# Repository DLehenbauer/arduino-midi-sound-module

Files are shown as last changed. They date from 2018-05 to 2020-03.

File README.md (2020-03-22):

# Arduino MIDI Sound Module
Turn your Arduino Uno into a 16-voice wavetable synthesizer/MIDI sound generator.

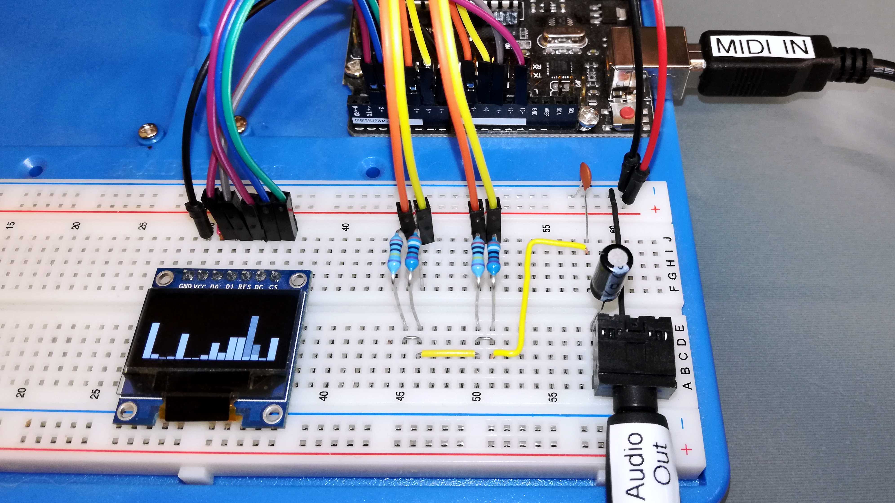
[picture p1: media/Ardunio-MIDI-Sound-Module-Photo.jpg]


# General MIDI Subset
Implements the most commonly used features of the General MIDI 1.0 standard, including:
* 128 standard instruments
* 45 percussion instruments
* 16 note polyphony with key velocity
* Note on/off, program change, pitch bend, channel volume, all notes and all sounds off.

# Demo

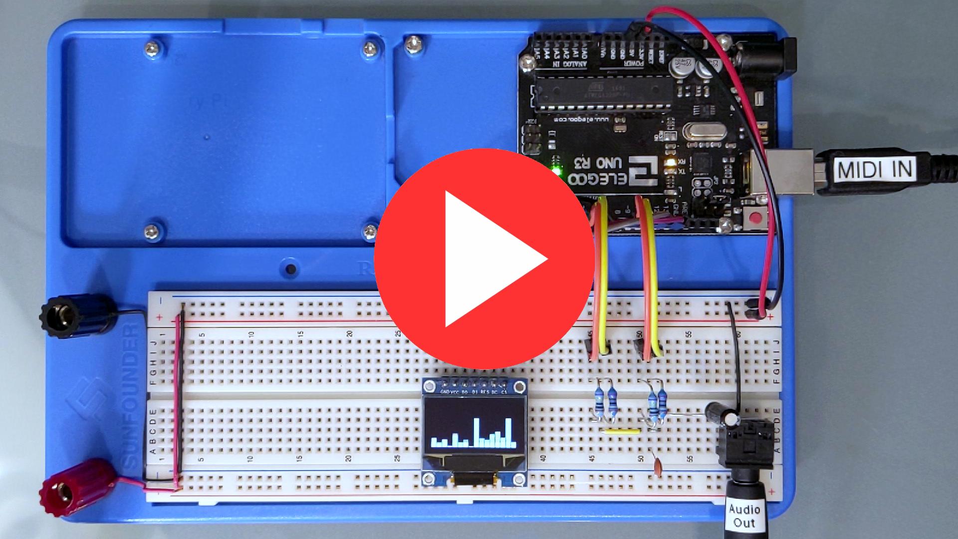
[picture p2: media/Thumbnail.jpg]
Arduino - Imperial March (Video) (https://www.youtube.com/watch?v=4pCgZSmhi4E)


# Synth Engine      
* 16 voices sampled & mixed in real-time at ~20kHz
* Wavetable and white noise sources
* Amplitude, frequency, and wavetable offset modulated by envelope generators
* Additional volume control per voice (used for channel volume and key velocity)
* Documented C++ code builds in Arduino IDE or Atmel Studio 6.0

# Hardware
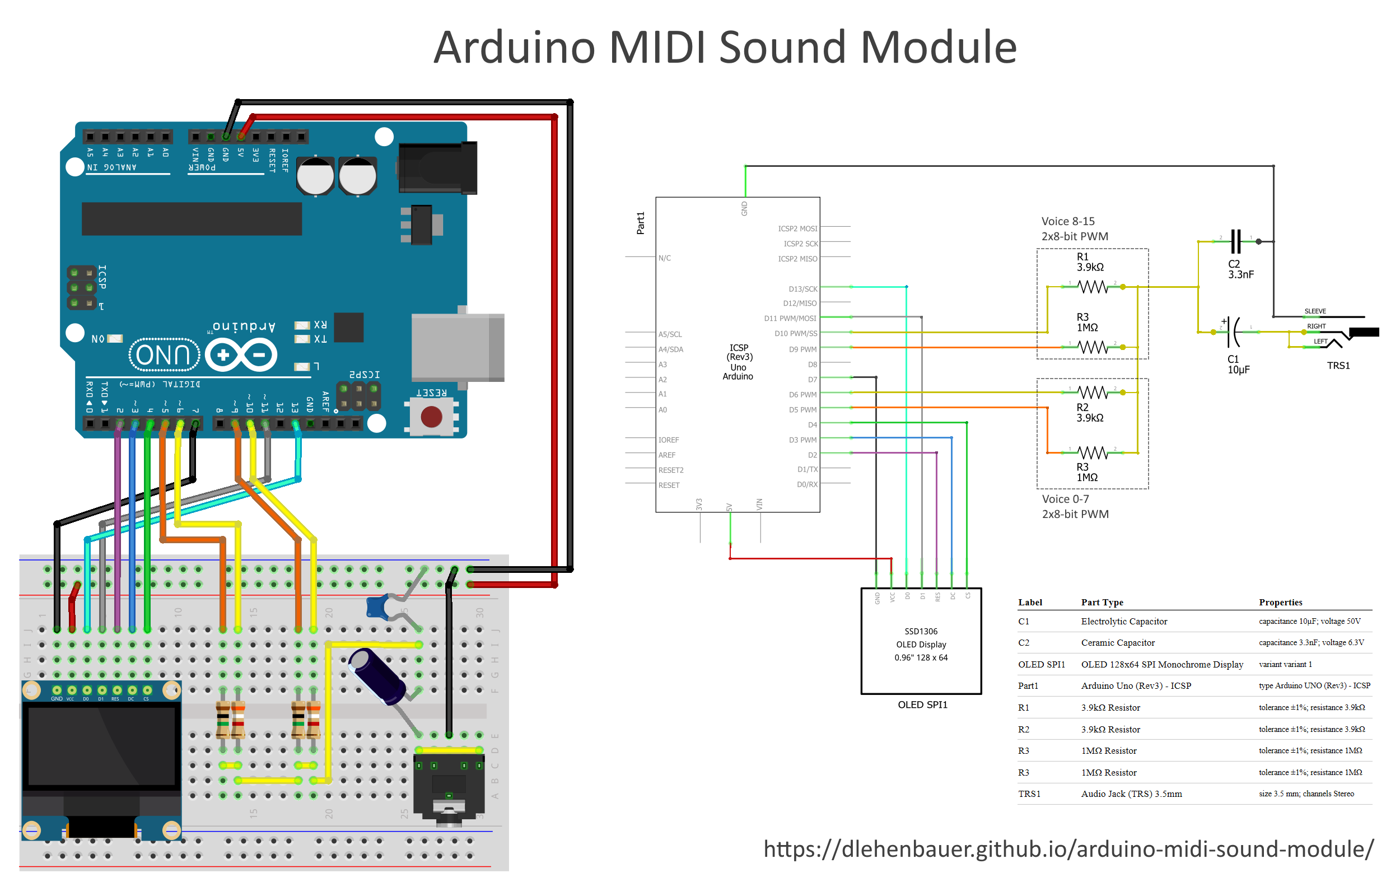
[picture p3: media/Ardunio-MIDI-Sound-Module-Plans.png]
Schematic


# Useful Tools
* [Hairless MIDI](https://projectgus.github.io/hairless-midiserial/) - Use default settings and `#define USE_HAIRLESS_MIDI`
* [The Kik Gen Labs - USBMidiKlik](https://github.com/TheKikGen/USBMidiKliK) - Do not `#define USE_HAIRLESS_MIDI`
* [loopMIDI](https://www.tobias-erichsen.de/software/loopmidi.html)

# Resources
* [Open Music Labs - PWM DAC](http://www.openmusiclabs.com/learning/digital/pwm-dac.1.html)
* [Open Music Labs - Dual PWM Circuits](http://www.openmusiclabs.com/learning/digital/pwm-dac/dual-pwm-circuits/index.html)

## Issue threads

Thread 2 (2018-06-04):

Thank you, and a Favor

nathanRamaNoodles, 2018-06-04:
I've seen your demo and was amazed that you perfected this feat on an Arduino Uno!
Since your code didn't get the respect it deserved I posted this project on [reddit and it was popular](https://www.reddit.com/r/arduino/comments/8oi1th/someone_pinch_me_this_guy_made_16_note_polyphonic/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).
Your welcome.
Also, I can see potential in your project.  I just have one favor; is there a way you could make the code to read a MIDI file from an SD card?  If so, then that would really make the Arduino community happy.

Thank you for your time.

DLehenbauer, 2018-06-06:
Thanks for the enthusiasm!

Embedding the MIDI file or reading from an SD card would be an interesting challenge.  As-is, the project does a pretty good job of utilizing every available resource of the Uno.  :)

Most of the MIDIs in my collection exceed the available memory on the Uno, so an SD card is probably the way to go.

The easiest solution would be to use a second Uno to play back the SMF, connecting serial out of the player to serial in of the synth.  (That by itself could be an interesting and useful stand alone project.)

Play back using a single Uno would require making some tradeoffs to free resources.  Here are some things I've considered or experimented with along the way:
* Reduce to 12 voices.  (Many MIDI files still play reasonably well w/12 note polyphony)
* Drop the OLED display.  (Neat demo, but may not be useful to the community.)
* Reduce the size of the wavetable by increasing reuse between instruments to free PRGMEM.
* Less convenient representation of envelope programs to reduce calculation cost.
* Share a single modulator for frequency/wavetable offset envelopes.  (Few instruments use both)
* Lowering the sample playback rate.

There are opportunities to preprocessing midi files to coalesce high frequency state changes, premultiply velocity and channel volume, filter unused data, etc. to compress and simplify playback.

A few more ideas that I think would be fun, but would make the project generally less accessible:
* Custom firmware on the 16u2 to preprocess midi (e.g., coalesce/premultiply pitch bends)
* Increase clock from 16 -> 20mhz by building on a breadboard.  (Uno is underclocked)
* Drop support for the Arduino IDE and/or distribute as precompiled binary.

(And of course, there's always the option of moving to a Teensy or Pi Zero...  but just seems too easy.  :)

Personally, I was posting the source/video because I didn't anticpate having time to tinker w/this project for a while, but it sounds like a really fun place to pick up again!  (Or a fun place for a collaborator to join. :D)

nathanRamaNoodles, 2018-06-06:
## My Background
Yeah, I love to tinker with Arduinos and play music with them.  Personally, my main goal was to make an Arduino mp3 player with skipping, pause/play and timing functionality.  Essentially, the arduino needs a library that allows it to play a music file(without the help of a computer), out to a speaker with polyphony.  The raspberry Pi already does this, so I want the Arduino to at least have some way to play polyphonic music in a crystal quality. I was interested in more voices but never had the ambition to learn assembly because...C++ is where it's at 😂.

  I'm a noob when it comes to timers and wavetable synthesis; I'm more comfortable with dealing with the aspect of time in general.  For example, in my MusicWithoutDelay library, I tested and came up with formulas that allowed me to pause during a song, without delay(non-blocking) :D

   I got more interested in time managing, so I tried to see if I could try skipping anywhere within the song.  So I did.  While I was there I got bored and made a function to play the music backward.  Yeah, I didn't know how to store MIDI files to an SD card and read it to the Arduino, so I used the most basic form of music files...RTTL(Ring Tone Transfer Language).  I never felt like going back to maintaining the library because not many people saw its usefulness.  I have better code that allows me to store the RTTL files to PROGMEM, and have used this [synth library](https://github.com/dzlonline/the_synth) to allow tetrapolyphony.  If your interested, I can update **the files on my Github for you to test**(I got Legend of Zelda I wrote by hand😫).

## Ok
Anyways, I'd love to be a collaborator for your project.  I'm still in college, but its something fun to do over the summer.

I still can't believe you managed to pull 16 note polyphony on a weak board like the Arduino.  I wonder what you'll do on the Arm Cortex MCU 😂.

I tried to read your code, and found a [library that allows reading MIDI files from an SD card](https://github.com/5shekel/midi.player).  But I had a hard time implementing it in your code.  **And Yes, we could send instruments.h to the SD card,** seems to eat the most memory.  A while ago, I figured out we can open multiple files at the same time, it takes 512 bytes of SRAM for one SD file, and then 50 bytes for every additional file opened.

DLehenbauer, 2018-06-07:
I was thinking the SMF (aka MIDI file) would need to go on the SD card.  The wavetable in instruments probably needs to stay in PRGMEM.  (We need to sample 16 x 256B waveforms in real-time in the sample/mix ISR, and there isn't enough SRAM to cache these from the SD card.)

The library you found would complete the other side of a two Arduino solution, where one Arduino produces MIDI messages by playing back an SMF from an SD card, and the other generates sound from incoming MIDI messages (just connect TX to RX).

Closed 2020-01-05.

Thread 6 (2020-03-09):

Display behaves differently on first play of midifile compared to subsequent plays

urbantigerau, 2020-03-09:
Hi,
Firstly thank you for developing this software. Given the hardware it runs on it is a remarkable achievement and it works really well.

I am working on a clock which I want to play the Westminster chimes, as per Big Ben in London, England. Having the clock play the respective MIDI files is a pleasing solution in terms of ability to get a good sound and be able to modify it. Your software makes that a proposition at a very reasonable cost compared to some of the Arduino MIDI solutions.

In the process of development I have encountered an odd phenomenon with the behavior of the display.

Please see the attached file which plays the hour chime melody followed by 6 hour strikes.  While I probably won't use the display in final implementation I am having trouble seeing why the display behaves as it does.
[west.zip](https://github.com/DLehenbauer/arduino-midi-sound-module/files/4304561/west.zip)

I am playing this file with Audacity configured to play into the LoopMIDI port then through the Hairless MIDI Serial Bridge to the Arduino which is on USB Port 7. The file plays as expected and sounds good. It is a very simple melody, effectively no chords and only one note at a time. The first time it plays the display shows notes sequentially across the voices as the notes play. First note shows on first voice, second on second voice and so on, until the 16 notes of the melody play out and all the hour strikes show on the first voice.

On all subsequent plays (until the Arduino is reset) the display shows notes on the first and second voices alternately, with the hour strike being on the first voice.

On first glance this looks like an initialization problem, and I started to look for that in the code. However this code, even the display part which is simpler, is complex as necessitated by what it does in such simple hardware. It seems to me that the display side of the code is correct and it is correctly reporting that each note is on a different voice for the first play. I cannot see why that is given the debug information from Hairless. See the attached image showing all notes going to channel 1.
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

I admit that this is not a desperate problem, but it is an interesting one and I hope you have the time to have a look.

Once again thanks for taking the time to develop such a great piece of software.

Kind Regards,
Fred.

DLehenbauer, 2020-03-11:
I'm glad to hear that you're enjoying the synthesizer!

You're correct that initialization is involved, but I think what probably makes the current behavior surprising is that the display is showing the amplitude of synthesizer voices, not MIDI channels.

A MIDI channel is roughly equivalent to an instrument.  One MIDI channel may play multiple notes simultaneously.

A synthesizer voice is an independent sound generator.  This synthesizer has 16 voices, which means it can play 16 notes simultaneously.

However, there is no practical limit on the number of notes a MIDI file may play simultaneously.  To handle this, synthesizers typically employ a [voice-stealing](https://www.sweetwater.com/insync/voice-stealing/)  heuristic.

The phenomena you're observing on the display is the output of this synthesizer's voice-stealing heuristic (see `getNextVoice()` in synth.h).

Initially, each voice has been "finished forever", so the heuristic prefers voices that have never been played.  After each voice has been played once, they begin to tie.

The reason you see some alternation between voices 1 & 2 is because after the `note off` messages, there is still a little bit of decay, so the note isn't quite finished yet.

(Hope this makes sense.)

For your application, you might find some of the following changes helpful:
- Reducing the number of voices to free up CPU cycles (if needed)
- Trimming the data in instruments_generated.h to free up flash memory (if needed)

Let me know if you'd like any tips on how to do that...  and good luck with your project!

Daniel

urbantigerau, 2020-03-12:
Thanks for you kind and informative reply Daniel, especially related to my project. The subtlety of voices vs channels is one I had missed but explains a lot. I have been referencing available  MIDI documents (like  http://www.music.mcgill.ca/~ich/classes/mumt306/StandardMIDIfileformat.html and https://www.midi.org/specifications-old/item/table-1-summary-of-midi-message) about file structure and had missed the voice concept and the relationship to channels. I will study it closely again.  I am sure I can learn more.

I particularly like the voice stealing behavior, very subtle. Your explanation completely describes the behavior I have observed. It would probably not perplex anyone with a more complex melody. It really only stands out with the simple chime I am using.

Thanks for the offer of trimming and reducing CPU cycles, I will take you up on it if I need that.

Again thanks for responding. I may have another question about silencing in mid-stream. If so I will open another issue as this is the best way for others to benefit from questions and the answers.

Thanks again for your assistance.

Regards,
Fred.

urbantigerau, 2020-03-12:
Hi Daniel,

I have replied on GITHUB to close the issue. Again thanks for a great explanation. I am contemplating another issue regarding silencing the snyth mid-stream but I may be able to sort it myself yet.

Please see attached document as regards the project I referred to.

I have attached a sound file so you can hear it as it is as described above

Thanks again for your assistance.

Regards, Fred.

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

Closed 2020-03-12.

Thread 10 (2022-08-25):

Hanging Note Bug

CometoDiner, 2022-08-25:
Hi !

In most midi files i hear a hanging note thru the whole time.
If i press stop, the hanging note is gone...

Best regards
Paddy

CometoDiner, 2022-09-09:
Hello again.

Is this project not longer supportet?

best regards
Tom

DLehenbauer, 2022-09-11:
Hi @CometoDiner - This project still seems to be working for me.  I can only think of a few possibilities:

One is that the MIDI file streams events so quickly that it overflows the ring buffer in the Arduino and a keyoff event is lost.  This certainly happens with [Black MIDIs](https://blackmidi.fandom.com/wiki/Home) and is kind of expected.  Black MIDIs will overflow many sound generators from the pre-USB era.

Another is that there is an instrument with an overly long or infinite sustain that is causing the note to be held until an explicit keyoff event, in which case we'll need to identify the offending instrument.

The third is that the files are using something other than keyoff to terminate the note.  (For example, I've seen keyon with a velocity of 0 used.)

If you want to share an example MIDI I can take a look and see if I can spot the problem.  For comparison, [commando.mid](https://www.vgmusic.com/music/computer/commodore/commodore/commando.mid) is an example of a fairly demanding MIDI file that plays correctly for me.

Here is my setup for comparison:
- Windows 10 x64
- [loopMIDI v1.0.16](https://www.tobias-erichsen.de/software/loopmidi.html) to create a virtual loopback device
- [Hairless MIDI v0.4](https://projectgus.github.io/hairless-midiserial/) at bridge to COM4 (don't forget to change baud rate to 38400, run as admin for FTDI devices)
- [Falcosoft Midi Player 6](http://falcosoft.hu/softwares.html#midiplayer) outputting to loopMIDI port.
- Source built today from [a8ad8e3](https://github.com/DLehenbauer/arduino-midi-sound-module/commit/a8ad8e36dbcc8a1c40ec63657f3fc3007a817d10) with [Arduino IDE 1.8.19](https://www.arduino.cc/en/software).

CometoDiner, 2022-09-11:
Hi Daniel !

Thanks for quick support.

The attached example files have all issues.

I’m using no usb with your project, i‘, develope an open source Project in vogon.com fort he community.

The Beepblaster Module (a Waveblaster compatible Synth.)

Pictures are attached.

Thanks for Supporting

Paddy

https://www.vogons.org/viewtopic.php?f=62&t=89000

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

DLehenbauer, 2022-09-12:
Hi @CometoDiner - When replying to emails from GitHub the response is appended to the GitHub issue without preserving file attachments ([here](https://github.com/DLehenbauer/arduino-midi-sound-module/issues/10#issuecomment-1242892473)).

Could you find another way to share some of the MIDI files?  (Perhaps a web link to the originals).

CometoDiner, 2022-09-13:
Hi DLehenbauer,

well, i see - here it is super extreme:
https://legendofmi.com/files/downloads/midis/theme.zip

best regards
Paddy

DLehenbauer, 2022-09-14:
Hi @CometoDiner - There is a sustained E-B-E on channel 4 (Drawbar Organ) at the beginning of the song from ~0:00:04 - 0:00:24.  I can see how that might be mistaken for a hang, but it's actually part of the song.  You'll hear the same with the Microsoft Wavetable GS Synth.

Was that what the issue you were referring to, or was there something different that didn't sound right to you?

CometoDiner, 2022-09-14:
Hi Daniel.

There are many midi files and examples of this error.
Many Midis also run without problems. It seems to be related to sustain.
This will not be stopped. Even if you stop the media player, the sustain continues.
This behavior only occurs with the Arduino. All other midi devices run without problems.

I use DOS - Win 98SE, and retro hardware. The beep blaster is connected to the
wavetable connector on the MPU-401. Other sound cards have been tried without success.

It is a real problem.
best regards
Paddy

CometoDiner, 2022-09-14:
Hi Daniel. Could you check gm1.1 Version from this Paket, please:
https://leejacksonaudio.lbjackson.com/html/download.html

Here is a Video as you can see:
https://youtu.be/PcJ1hsm590E

best regards
Paddy

DLehenbauer, 2022-09-14:
I'm sorry to tell you this, but that MIDI file seems to play correctly as well using the setup I [described earlier](https://github.com/DLehenbauer/arduino-midi-sound-module/issues/10#issuecomment-1242838578).

From your description above, I gather you're using 5-pin MIDI plug to send the data?  If so, did you remember to comment out the '#define' in 'arduino-midi-sound-module.ino' to set the baud rate to 31250?

```cpp
// Defining 'USE_HAIRLESS_MIDI' will set the serial baud rate to 38400.  Comment out the
// below #define to use standard MIDI speed of 31250 baud.
#define USE_HAIRLESS_MIDI       // <-- You should comment this out if using 5-pin MIDI
```

(You'll have to rebuild/reupload the sketch afterward.)

If you've already done this, the next place I would look is the how you are interfacing the Arduino.  Are you using the circuit described in MIDI.h?

```
    Option #3: 5-pin DIN
    --------------------

    You can also build a 5-pin DIN serial MIDI input port for the Arduino and use a standard serial MIDI interface.

    NOTE: Remember to comment-out '#define USE_HAIRLESS_MIDI', per note at top.

                220
        .------^v^v^----------o-------.                      .----o--------------o----< +5v
        |                     |       |                      |    |              |
        |     .-----.         |  1    |      .--------.      |   === 100nF       /
        |    / 5-DIN \       _|_ N    o----1-|        |-6----'    |              \
        |   |  (back) |       ^  9    o----2-| H11L1* |-5---------o--< Gnd       / 280
        |   |o       o|      /_\ 1    |      |        |-4----.                   \
        |    \ o o o /        |  4    |      '--------'      |                   /
        |     /-----\         |       |                      |                   |
        |  4 /       \ 5      |       |                      '-------------------o----> RX
        '---'         '-------o-------'

    Notes:
        * H11L1 is a PC900 equivalent
```

PS - I would very much like to see your video, but you'll need to make it non-private.

CometoDiner, 2022-09-15:
Hi Daniel.

Now you can watch the Video.
MIDI Signal is already 5V TTL, i don`t use  5pin Midi plug.
Baud rate is also correct.

best regards
Paddy

CometoDiner, 2022-09-16:
Hello Daniel :-)

The phenomenon is just as reproducible. I built a switch in the 5V
line to turn the Arduino off/on. It's the same notes and always the same error.
The error is always the same with other midi files.

best regards
Paddy

CometoDiner, 2022-09-16:
Is it Easy possible to deactivate sustain support to see if that's the Problem?
I think it may help you.

best regards
Paddy

DLehenbauer, 2022-09-16:
It works the other way around: all instruments are sustained until they receive a MIDI event that tells them to stop playing.

Typically, it's a 'NoteOff' event that releases a note on a channel.  There is also an extended 'AllNotesOff' command that releases all notes on a channel and 'AllSoundOff' that releases the notes and sets the channel volume to zero.
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
CometoDiner, 2022-09-16:
Hi Daniel

Hmmm. I can rule out the MPU 401 as the cause, since other wavetable cards work without problems on it,
and the error on the Arduino also occurs when it is connected to other sound cards.

I've ordered new boards where the TX from the MPU first runs through an optocoupler,
maybe the signal isn't "clean" enough.

Let's wait and see what the result is, I'll get back to you - it will take about 2 weeks.

best regards
Paddy

DLehenbauer, 2022-09-16:
I was thinking it might be a signal integrity issue also until you mentioned it was deterministic.  Now I'm wondering if the sound card or the media player is changing the MIDI event stream.  For example, perhaps the MIDI file uses some extension that the older player/card misinterprets, causing a few events to be dropped.

Do you have a schematic for your board?  (You can paste images into GitHub issues).  Are you perhaps not using an Arduino Uno, but instead have an Atmel 328p directly on the board?

CometoDiner, 2022-09-17:
I don't think the midiplayer changes the stream. Then other Midi devices would also be affected. I attached the schematic, and yes, the 328p is right on the board.
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

CometoDiner, 2022-09-24:
Hi Daniel.

Same problem with optocoupler version. It must be a software issue.

best regards
Paddy

DLehenbauer, 2022-10-01:
Yeah, since you say the problem is deterministic, I wasn't too hopeful that it was a signal integrity issue, but thank you for trying it.

I can only think of a few ways in which you and I could get different results:
1.  We're running different firmware on the 328P.
2.  A difference in hardware.
3.  A difference in the bitstream sent to RX (the blue wire in the photo).

The first could happen if you checkout out a different commit, or if the version of the Arduino IDE your using bundles a different GCC or uses different compiler options.  (I think unlikely, but it's possible.)

Regarding a hardware difference, your schematic looks right to me, and I've successfully run this project in the past with a 328P on a breadboard.  The one idea I had is if your crystal frequency isn't 16.0 MHz, in which case you'll need to adjust F_CPU or the USART baud rate will be wrong (see midi.h).

Regarding a difference in bitstream, there is a lot of different software and hardware between the contents of the MIDI file and the RX pin of the 328P.  It may be that something in that chain of media player, driver, and hardware is altering the stream in a way the firmware doesn't handle well.

To try to get a little closer to your setup, I switch to a 5-pin MIDI interface, which puts me at 31250 baud and removes Hairless MIDI and loopMIDI from my setup:

- Windows 10 x64
- [Falcosoft Midi Player 6](http://falcosoft.hu/softwares.html#midiplayer) (also tried [TMIDI](https://grandgent.com/tom/projects/tmidi/))
- [MIDIPlus TBOX 2x2](http://www.midiplus.com/html/tbox.html) with Microsoft's generic driver.
- 5-pin MIDI to RX interface as described in [midi.h](https://github.com/DLehenbauer/arduino-midi-sound-module/blob/master/arduino-midi-sound-module/midi.h)
- Undefine USE_HAIRLESS_MIDI in [arduino-midi-sound-module.ino](https://github.com/DLehenbauer/arduino-midi-sound-module/blob/master/arduino-midi-sound-module/arduino-midi-sound-module.ino) to use 31250 baud
- Source built from [a8ad8e3](https://github.com/DLehenbauer/arduino-midi-sound-module/commit/a8ad8e36dbcc8a1c40ec63657f3fc3007a817d10) with [Arduino IDE 1.8.19](https://www.arduino.cc/en/software).

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

Unfortunately, the song still plays correctly for me.

I'll keep thinking about it, but at this point my suggestion would be to try to divide and conquer.  If you can, build the working configuration using a modern PC, generic MIDI interface, and a standard Uno like I have in the photo above.  Then try substituting your Waveblaster board.  If your waveblaster board works with the modern software/hardware, we know it's the third issue: something is modifying the bitstream.  If the problem replicates with your board, then we know it's different firmware or a subtle hardware difference.

CometoDiner, 2022-10-22:
Hi Daniel.

The Problem is solved. I used all the time the MPU401 Driver from Microsoft (in Win98SE).
With this driveryou have this issues all the time.
But when i use the original Roland MPU401 Driver for the NON-PNP Card.
the issue is gone.

It was a Driver Problem ;-)

best regards and thanks so much for your Support

Paddy

DLehenbauer, 2022-10-24:
Whew!  Glad you were able to figure it out!

Thanks for letting me know.  I'll go ahead and close this issue.

Closed 2022-10-24.

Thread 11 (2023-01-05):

Implementing Stereo (Controller Change 10)

aspiringnobody, 2023-01-05:
Daniel,

I've got my breadboard of what you've outlined working wonderfully.  Thanks for the awesome project!  As a sort of beginner programming challenge I want to implement stereo using a second Arduino.  I'm using input option 3, so both Arduino can listen to the same incoming midi stream (no need to try to send data from one to the other).  If a midi signal implements panning then each Arduino would scale the volume by the appropriate value.

I've been digging through the source trying to follow (beginner C++ project for me, so trying to follow is half the battle) and it seems like I need to:

- add a case in midisynth.h (0x0A) to handle incoming pan messages
- offset the 0-127 value by 64 to get the "leftness" or "rightness" value as a 6-bit integer (perhaps looking at the high bit to determine if I need to reduce volume on the left or right side and the lowest six bits can be used directly as the multiplier on one Arduino and inverted on the other?? still working this out in my head...)
- add a declaration to the .ino to build for let or right channel so I can decide which offset/multiplier to use from point above
- potentially scale that integer to be 8 bits  to make it easier to merge with the velocity and channel volume
- figure out how to modify mixVolume to scale by my multiplier  (I'm a bit unsure about how to go about this, since it seems like you've gone to some length to reduce the computational overhead of this by using some clever bit shifting instead of doing it a more straightforward way.  Perhaps I need to add another stage (but I'm not sure if this would be fast enough or if there's a way to do it in one operation that would still be fast):
```
uint8_t monoVolume(uint8_t volume, uint8_t velocity) {
// Map 8-bit channel volume and 7-bit velocity to 7-bit mono volume.  We've scaled MIDI
// channel volume up to 8-bit so that we can perform an inexpensive '>> 8'.
return (static_cast<uint16_t>(volume) * static_cast<uint16_t>(velocity)) >> 8;
}
uint8_t mixVolume(uint8_t mixVolume, uint8_t stereoMultiplier) {
// Map 8-bit stereo multipler value and 7-bit mono volume to 7-bit final mix volume.
return (static_cast<uint16_t>(mixVolume) * static_cast<uint16_t>(stereoMultiplier)) >> 8;
}
```

Before I get off the deep end here, does that seem like a reasonable approach to take and do you have any advice to the above?

If this is too much feel free to close.  Thanks again for making such a cool project!

Edit: presumably I'd want to drive both Arduinos from the same clock eventually so if it was converted to mono signal the samples would stay in phase.

aspiringnobody, 2023-01-05:
Closing this.  It looks like mixVolume needs to be updated so that every time setVolume is called it respects the pan scalar.  I've made a fork and I'm going to play with it on my own but this would likely need someone much past beginner level to modify midisynth.h and synth.h to always respect the new scalar -- and also it would add significant computational overhead.  Probably not feasable.

aspiringnobody, 2023-01-06:
I was actually able to make this work, surprisingly since this is the first thing I've touched in C++ since college 18 years ago.  I'll clean up my fork in the next few days and send you a pull request.

For anyone curious, I uploaded an MP3 of what it sounds like playing a song from FF7 to Vogons:
[https://www.vogons.org/viewtopic.php?f=62&t=89000&p=1130478#p1130478](url)

Closed 2023-01-05.

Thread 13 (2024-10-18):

Document how to generate instruments

korakinos, 2024-10-18:
Do you have any documentation about how to generate the instrument code for instruments_generated.h? This could be handy to customize the code with different sound samples, effectively using the programme as a sampler.

PS: This repository is a gem. The documentation in the code comments is super helpful, and I love how the module sounds, especially the subtly staggered decay of sounds and how my keyboard's topmost two octaves come out completely out of tune, prepared-piano style (which could be a bug report, but as I said, I love it). Thank you!

DLehenbauer, 2024-10-20:
I'm sorry, there is no documentation.  To create the 'instruments_generated.h' file I cobbled together a clunky and unintuitive UI editor.  It's a React web app that uses Emscripten to compile the synthesizer to JavaScript so you can test instruments without having to recompile / deploy to an Arduino.

It's not suitable for release, but I can share the private repo with you if you'd like to try to rejuvenate it.  (It was a super early use of WebAudio before things had completely stabilized, and probably needs some tweaking to get it working again on today's browsers.)

korakinos, 2024-10-21:
> I'm sorry, there is no documentation.

That's okay!

> It's not suitable for release, but I can share the private repo with you if you'd like to try to rejuvenate it.

Since I am not familiar with the tech stack you used (not a single part of it), I would
most probably not try to get your code running, but to understand what it does and write my own version. And I may never get around to that, either. If you are okay with all this, I would be happy to take a look at your repo. If not, then no worries; I can still study the generated Arduino code.

DLehenbauer, 2024-10-21:
@korakinos - I don't know how helpful it will be, but I'm happy to share.  I've added you as a collaborator to the 'arduino-midi-sound-module-editor' project.  (You may need to accept via an email)

The 'main' branch of the repository is empty.  The code resides in the 'dev' branch:
https://github.com/DLehenbauer/arduino-midi-sound-module-editor/tree/dev

Under the '/src/components' directory are the various UI editors that manipulate data structures under 'model.persistant.synth'.  The instruments and envelope editors are probably the most interesting.

The 'instruments_generate.h' file is produced by serializing these data structures here:
https://github.com/DLehenbauer/arduino-midi-sound-module-editor/blob/dev/src/routes/code/index.js#L120

korakinos, 2024-10-22:
I got the invitation and will take a look. Thank you for being so forthcoming!

Closed 2024-10-22.

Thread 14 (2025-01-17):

Upgrade to I2s

habuenav, 2025-01-17:
Hello, excellent project, my total respect and admiration. Have you thought about porting it to another board with an i2s output, perhaps the esp32?

DLehenbauer, 2025-01-21:
Thanks!  I do not currently have any plans to port the project to another platform, but I am supportive if anyone else is interested in doing so.

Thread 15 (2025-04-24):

Just curious - why are OCR1A/1B swapped relative to OCR0A/0B?

gilesp1729, 2025-04-24:
I have been studying your code with a view to implementing on a Mega2560 and interleaving with keyboard scanning.
In the following (dac.h)

`  static void set0to7(int16_t out) {
    uint16_t u = static_cast<uint16_t>(out) + 0x8000;
    OCR0A = u >> 8;
    OCR0B = u & 0xFF;
  }

  static void set8toF(int16_t out) {
    uint16_t u = static_cast<uint16_t>(out) + 0x8000;
    OCR1B = u >> 8;
    OCR1A = u & 0xFF;
  }
`
Just wondering why 0B is bottom the  byte for 0to7, but 1A is the bottom for 8toF. Is it to do with the carrier frequency cancelling?

DLehenbauer, 2025-04-25:
No, it's nothing that fancy. :-)

All four PWMs operate independently, so the mapping is arbitrary as long as low bytes are connected to 1M resistors and high bytes to 3.9k resistors.

I chose a mapping that seemed natural to me based on the Arduino's pin names:

**Voices 0..7 uses D5 (lo) / D6 (hi)**
Lo Byte → OCR**0B** → Pin **D5** → 1M resistor
Hi Byte → OCR**0A** → Pin **D6** → 3.9k resistor

**Voices 8..F uses D9 (lo) / D10 (hi)**
Lo Byte → OCR**1A** → Pin **D9** → 1M resistor
Hi Byte → OCR**1B** → Pin **D10** → 3.9k resistor

gilesp1729, 2025-04-26:
Thanks Daniel.

DLehenbauer, 2025-04-28:
NP.  Good luck with your project!

Closed 2025-04-28.

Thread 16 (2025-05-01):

Support Mega2560 board

gilesp1729, 2025-05-01:
I have a solution for this issue - it's a small change to dac.h . I'd send you a PR, but github makes it very cumbersome to PR one commit out of many.

[dac.zip](https://github.com/user-attachments/files/20006656/dac.zip)

DLehenbauer, 2025-05-03:
I'm happy to commit the change for you, but before I do, I wanted to double-check that you didn't want credit for the change?  (If you're the one who submits the PR, you'll show up as a project contributor.)

I see you already have a fork.  To create a PR you'll need a branch at the head of the upstream repo.

* For safety, create a 2nd clone of your fork in a new directory (`git clone https://github.com/gilesp1729/midi-sound-library.git <some-directory>`).
* 'cd' into the above directory.
* Add a remote for the upstream repo (`git remote add upstream https://github.com/DLehenbauer/arduino-midi-sound-module.git`)
* Fetch changes from the upstream repo (`git fetch --all`)
* Checkout a new branch at the head of the upstream repo `git checkout -B mega2560 upstream/master`

You are now in a 'mega2560' branch that is identical to master in my repo. Now to make push the changes:

* Apply your changes to dac.h
* Commit the changes to your 'mega2560' branch (`git add dac.h` and `git commit -m "Add support for Mega2560 board"`)
* Push the mega2560 branch to your fork on GitHub (`git push origin mega2560`)

You can now go to your fork on GitHub and create the PR:

* Navigate to your fork (https://github.com/gilesp1729/arduino-midi-sound-module)
* Select the "Pull requests" tab at the top
* Click "New Pull Request"
* Create a PR to "DLehenbauer/arduino-midi-sound-module" master (left) from "gilesp1729/arduino-midi-sound-module" mega2560 (right).

(If the PR preview shows a bunch of changes instead of just dac.h, it's because you have the 'master' branch selected instead of the 'mega2560' branch.)

Again, if you don't want to mess with this I'm happy to do the commit...  but thought it was worth asking.  Just let me know.  :-)

gilesp1729, 2025-05-03:
Done. Thanks for the hand-holding - I'm more used to using TortoiseGit on Windows than the cmd line.

DLehenbauer, 2025-05-10:
Merged the PR.  TY!

Closed 2025-05-10.

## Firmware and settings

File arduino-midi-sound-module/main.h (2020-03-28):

/*
    Main 'setup()' & 'loop()' definitions, shared with main.cpp and *.ino
    https://github.com/DLehenbauer/arduino-midi-sound-module

    For schematics, see:
      dac.h          - Audio output circuit
      midi.h         - MIDI input options, serial driver, and midi dispatch
      ssd1306.h      - OLED display connections and driver

    For more sound generation, see:
      synth.h        - Core synth engine
      envelope.h     - Flexible envelope generator used to modulate amp, freq, and wave
      midisynth.h    - Extends synth engine w/additional state for MIDI processing
      instruments*.h - Wavetable and envelope generator programs for GM MIDI instruments
*/

#ifndef MAIN_H_
#define MAIN_H_

// NOTE: The *.ino file '#defines USE_HAIRLESS_MIDI', so if you built this from an Arduino
//       IDE sketch, you're configured to use Hairless MIDI at 38400 baud by default.
#ifdef USE_HAIRLESS_MIDI
  #define MIDI_BAUD 38400
#else
  #define MIDI_BAUD 31250
#endif

#include <stdint.h>
#include "midi.h"
#include "ssd1306.h"
#include "midisynth.h"

Ssd1306</* rotate 180: */ true> display;    // SSD1306 driver for 128x64 OLED SPI display
MidiSynth synth;

// The below thunks are invoked during Midi::Dispatch() and forwarded to our MidiSynth.
void noteOn(uint8_t channel, uint8_t note, uint8_t velocity)		    { synth.midiNoteOn(channel, note, velocity); }
void noteOff(uint8_t channel, uint8_t note)							            { synth.midiNoteOff(channel, note); }
void sysex(uint8_t cbData, uint8_t data[])							            { /* do nothing */ }
void controlChange(uint8_t channel, uint8_t control, uint8_t value) { synth.midiControlChange(channel, control, value); }
void programChange(uint8_t channel, uint8_t value)					        { synth.midiProgramChange(channel, value); }
void pitchBend(uint8_t channel, int16_t value)						          { synth.midiPitchBend(channel, value); }

// Invoked once after the device is reset, prior to starting the main 'loop()' below.
void setup() {
  display.begin();                        // Initializing the display prior to start the synth ensures that
  display.reset();                        // the display has exclusive access to SPI during 'setup()'.
  display.setRegion(0, 127, 0, 7, 0);     // (Note: 7 -> pages 0..7, each page being 8px, for 64px total.)
  
  synth.begin();                          // Start synth sample/mixing on Timer2 ISR

  Midi::begin(MIDI_BAUD);                 // Start receiving MIDI messages via USART.
  
  sei();                                  // Begin processing interrupts.
}

// Helper used by main 'loop()' to set each column of an 8x7 block of pixels to the given mask,
// and then dispatch any MIDI messages that were queued while the SPI transfer was in progress.
//
// Note: Because this is the only call to 'display.send7()', AVR8/GNU C Compiler v5.4.0 will
//       inline it (even with -Os), and then jump into Midi::dispatch().
void display_send7(uint8_t mask) {
  display.set7x8(mask);                       // Set first 7 columns of currently selected 8x8 block to given 'mask'.
  Midi::dispatch();                           // (Drain the pending queue of MIDI messages)
}

// There are four activities happening concurrently, roughly in priority order:
//
//    1. The USART RX ISR started by Midi::begin() is queuing incoming bytes from the serial port
//       in a circular buffer for later dispatch.
//
//    2. The Timer2 ISR started by synth.begin() is sampling/mixing and updating the output
//       waveform (by default, at ~20khz).
//
//    3. The main 'loop()' below interleaves the following two activities:
//        a. Handling the MIDI messages queued by the USART RX ISR by updating the state of the synth.
//        b. Updating the bar graph on the OLED display with the current amplitude of each voice.
//
void loop() {
  Midi::dispatch();                           // Each time through the loop, we drain the circular buffor of pending MIDI
                                              // messages.

  static uint8_t voice = 0;                   // Each time through the loop, we alse update the amplitude bar for one voice
  voice++;                                    // in round-robin order.
  voice &= 0x0F;

  uint8_t y = synth.getAmp(voice);            // The height of the bar is equal to 1.5x the current amplitude,
  y += y >> 1;                                // with a maximum of 64px (i.e., [0..63])
  y &= 0x3F;
  
  const uint8_t x = voice << 3;               // Calculate the left edge of the bar from the voice index.
  const int8_t page = 7 - (y >> 3);           // Calculate the 8px page that contains 'y'.
  
  display.select(x, x + 6, 0, 7);             // Select the 7px x 64px area of the display containing the current bar.
   
  for (int8_t i = page; i > 0; i--) {         // Clear 7x8 blocks above the new bar graph's current level.
    display_send7(0x00);
  }
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

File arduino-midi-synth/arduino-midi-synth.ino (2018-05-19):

/*
    Arduino Midi Synth v0.1
    https://github.com/DLehenbauer/arduino-midi-sound-module
    
    This sketch turns an Arduino Uno into a 16-voice wavetable synthesizer functioning as a
    MIDI sound module.  Typical usages include generating sound for a MIDI keyboard controller
    or playback of MIDI files.
    
    The MIDI synth implements the most commonly used features of the General MIDI 1.0 standard,
    including:
    
      - 128 standard instruments
      - 45 percussion instruments
      - Key velocity
      - Pitch bend
     
    (See open GitHub issues for caveats: https://github.com/dlehenbauer/arduino-midi-synth/issues)
      
    The synth engine features:
      - 16 voices sampled & mixed in real-time at ~20kHz
      - Wavetable and white noise sources
      - Amplitude, frequency, and wavetable offset modulated by envelope generators
      - Additional volume control per voice (matching MIDI velocity)
    
    The circuit:
    
                        1M*                    10uf**
            pin 5 >----^v^v^----o--------o------|(----> audio out
                                |        |
                       3.9k*    |       === 3.3uf***
            pin 6 >----^v^v^----o        |
                                        gnd
                                        
        * Use 1% resistors, ideally ordering extras and selecting the pair of 1M and 3.9k that
          most closely matches a 1:256 ratio (or adding a trim pot to get the precise ratio):
          http://www.openmusiclabs.com/learning/digital/pwm-dac/dual-pwm-circuits/index.html
          
       ** A/C coupling capacitor can typically be omitted (most audio inputs remove DC bias).
       
      *** Low pass RC filter capacitor can be adjusted to taste:
     
                               8kHz      10kHz      30kHz
                    2.2nf ~=  -0.7db    -1.1db     -5.6db
                    3.3nf ~=  -1.5db    -2.2db     -8.4db
                    4.7nf ~=  -2.7db    -3.6db    -11.1db

    Sending MIDI data to the Arduino:
    
    The easiest/fastest way to send MIDI data from your computer is to use a MIDI <-> Serial Bridge:
    http://projectgus.github.io/hairless-midiserial/

    (To avoid overrunning the small buffer for incoming MIDI data, set the lower the baud rate of
    hairless to 38400.  You will also need to adjust the baud rate of the Midi driver to match.)
    
    If you have an ISP programmer and an Uno R3 w/ATMega82U, you can make your Arduino Uno appear
    as a native USB MIDI device:
    https://github.com/kuwatay/mocolufa
    
    Finally, with a bit more circuitry, you can add an 5-pin DIN serial MIDI input port to the
    Arduino and use a standard serial MIDI interface.
    
                220 
        .------^v^v^----------o-------.                      .----o--------------o----< +5v
        |                     |       |                      |    |              |
        |     .-----.         |  1    |      .--------.      |   === 100nF       /
        |    / 5-DIN \       _|_ N    o----1-|        |-6----'    |              \ 
        |   |  (back) |       ^  9    o----2-| H11L1* |-5---------o--< Gnd       / 280
        |   |o       o|      /_\ 1    |      |        |-4----.                   \
        |    \ o o o /        |  4    |      '--------'      |                   /
        |     /-----\         |       |                      |                   |
        |  4 /       \ 5      |       |                      '-------------------o----> RX
        '---'         '-------o-------'
        
    Notes:
        * H11L1 is a PC900 equivalent
*/

// Defining 'USE_HAIRLESS_MIDI' will set the serial baud rate to 38400.  Comment the #define
// out to use MIDI standard 31250 baud.
#define USE_HAIRLESS_MIDI

#include "main.h"

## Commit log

2018-05-19 Move "drivers/..." to root so sources appear in Arduino IDE
2018-05-20 Move sketch to appropriately named subfolder
    The Arduino IDE requires that a sketch be located in a folder of the same name. When opening a file that does not meet this sketch/folder name matching requirement the Arduino IDE presents a dialog:
    The file "arduino-midi-synth.ino" needs to be inside a sketch folder named "arduino-midi-synth".
    Create this folder, move the file, and continue?
    After clicking "OK" the Arduino IDE currently moves only the file arduino-midi-synth.ino to the new folder, leaving behind the other source files. This causes compilation of the sketch to fail:
    arduino-midi-sound-module-master\arduino-midi-synth\arduino-midi-synth.ino:82:18: fatal error: main.h: No such fi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
    [arduino-midi-synth.ino]
2018-05-20 Rename 'arduino-midi-synth' subdirectory to 'arduino-midi-sound-module'
2020-01-05 Release v0.2 - Standardizing on 2x16 PWM (#4)
    * Finalize on 2x16 bit PWM DAC on Timers 0 and 1
    * Support MIDI channel volume (control command 0x07)
    * Trim unused space in wavetable (fix issue #3)
    [Arduino MIDI Sound Module.fzz]
2020-01-05 Add missing thumbnail
    [Arduino MIDI Sound Module.fzz]
2020-03-22 Remove suspend()/resume() when updating display
    This is no longer necessary now that we've finalized using PWM instead of sharing the SPI bus with a DAC.
    [main.cpp, main.h]
2020-03-26 Avoid Arduino core runtime (less mem/more perf)
    [main.cpp, main.h]
2020-03-26 Coalesce pitch bends to avoid stalls
    [main.cpp]
